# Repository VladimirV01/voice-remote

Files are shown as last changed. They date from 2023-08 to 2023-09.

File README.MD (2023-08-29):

# Voice Remote for Home Assistant
This is a ESPHome based device which can interact with voice assistants configured in Home Assistant. 

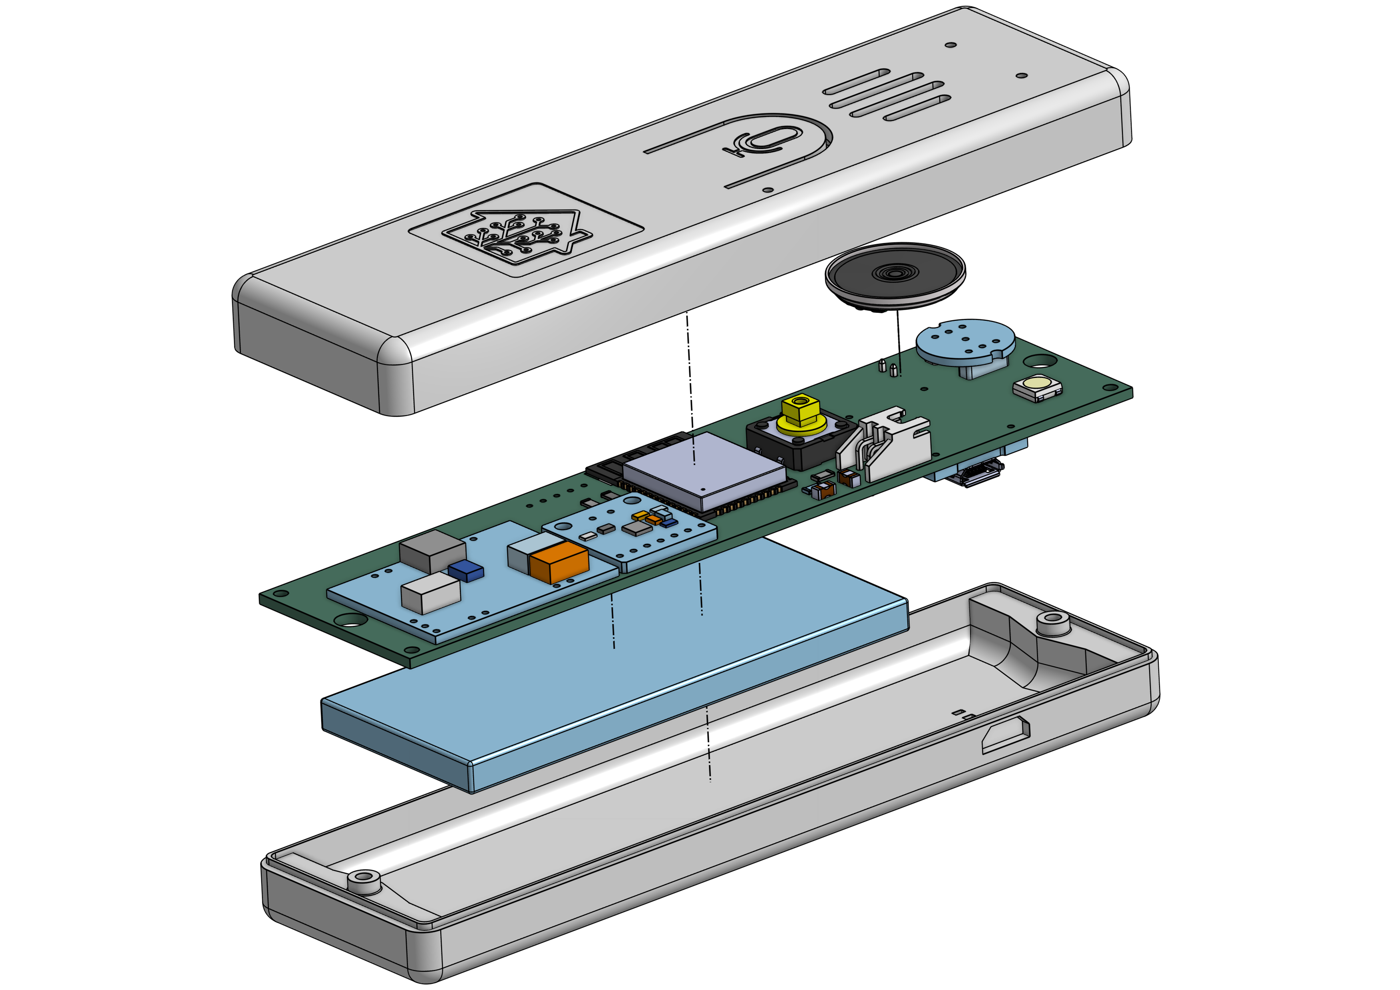
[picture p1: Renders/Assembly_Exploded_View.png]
Assembly Assembly Exploded View


## Project Timeline
Initially, I thought about this kind of project when I saw [$13 voice remote for Home Assistant](https://www.home-assistant.io/voice_control/thirteen-usd-voice-remote/) article. 

I tried to buy one **M5Stack ATOM Echo Development Kit**, but at that time it was out of stock almost everywhere I looked and it was pretty hard to source in my country. As a result, this idea transitioned to PENDING state until I manage to get an M5Stack or find a different approach. 

Some time later, thanks to the gods of youtube algorithms :smile:, I found a [video](https://www.youtube.com/watch?v=EeUG3Si9fZk) where the author describes very well an alternative for the **M5Stack ATOM kit** using **ESP32** based development board called **Adafruit Feather v2 ESP32 board**, which again was not very easy to find and source from my country.

So I decided to make my own adaptation of the project using plain ESP32 module and a custom PCB, because I like to design PCBs and I like when my projects are nice and tidy. 

___

### Main Components
- ESP32-WROOM Module
- INMP441 I2S MEMS Microphone Module
- MAX98357A I2S Amplifier
- TPS63020 Buck-Boost Converter Module
- WS2812 Addressable LED
- A tactile switch that you like (I used B3F-4055)
- A small speaker of your choice (I used AS02008MR)
- TP4056 Li-Ion Charging Module
- A Li-Ion battery (I used one from an old iPhone due to the form factor)
- Other miscellaneous components like SMD Resistors, Capacitors, etc.
___
### Case
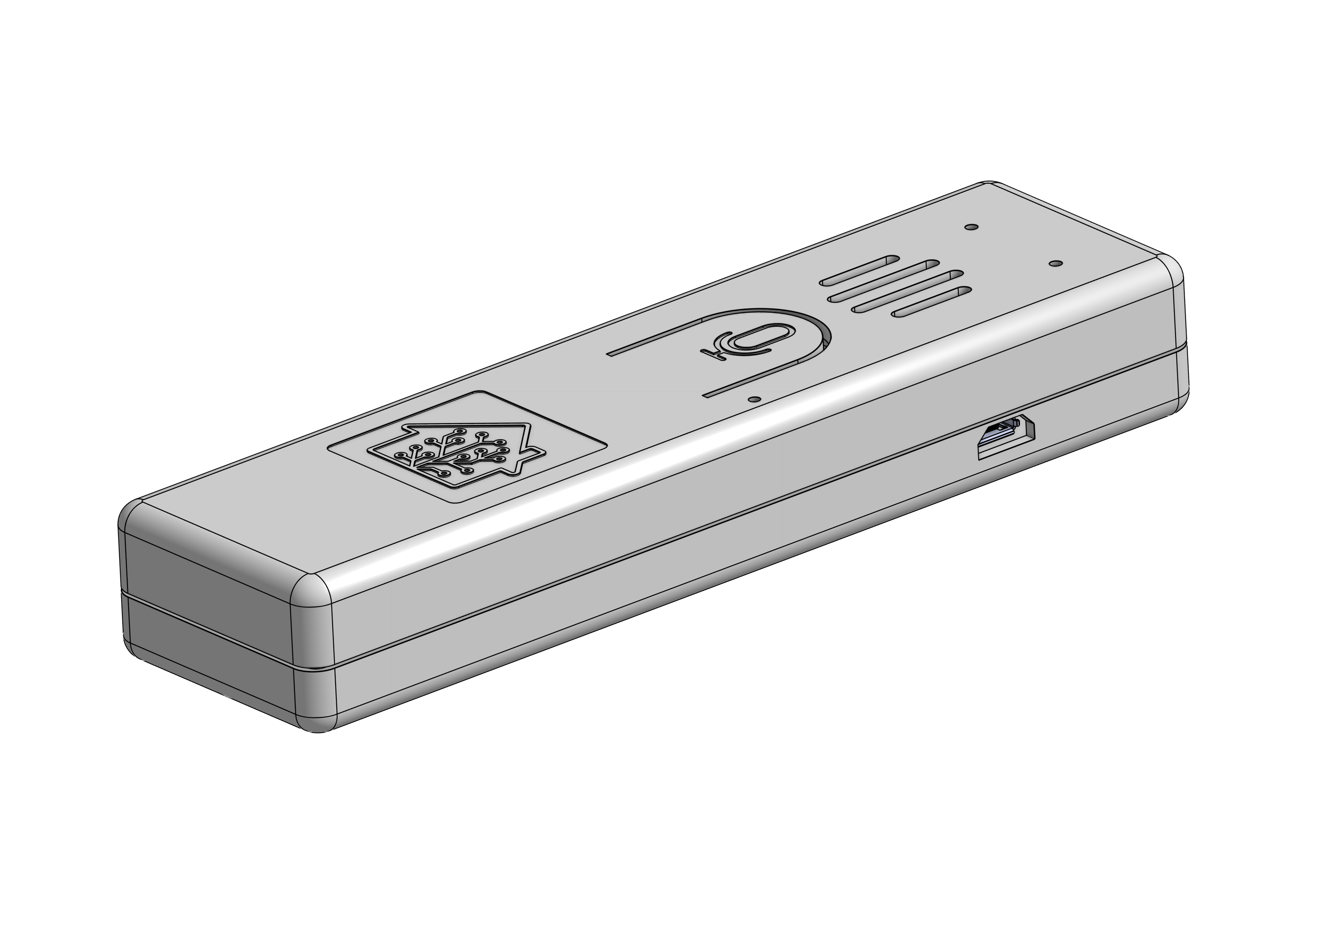
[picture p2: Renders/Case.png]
Case The Case

The case can be printed on a 3D printer without using any support, the files are attached in the "Case STL" folder. 

Also [here](https://cad.onshape.com/documents/a099e547f9d236687422ab01/w/ca8a76f6cc6eaf7c9584012f/e/bb01b9a7f8b48ed9828aac3d) is the link to the OnShape project. Anybody can make a copy and edit it if you want to make some changes to the case that will better suit your use-case.
___

### PCB
The printed circuit board was designed by me and I manufactured it using JLCPCB services and it turned out amazing. 
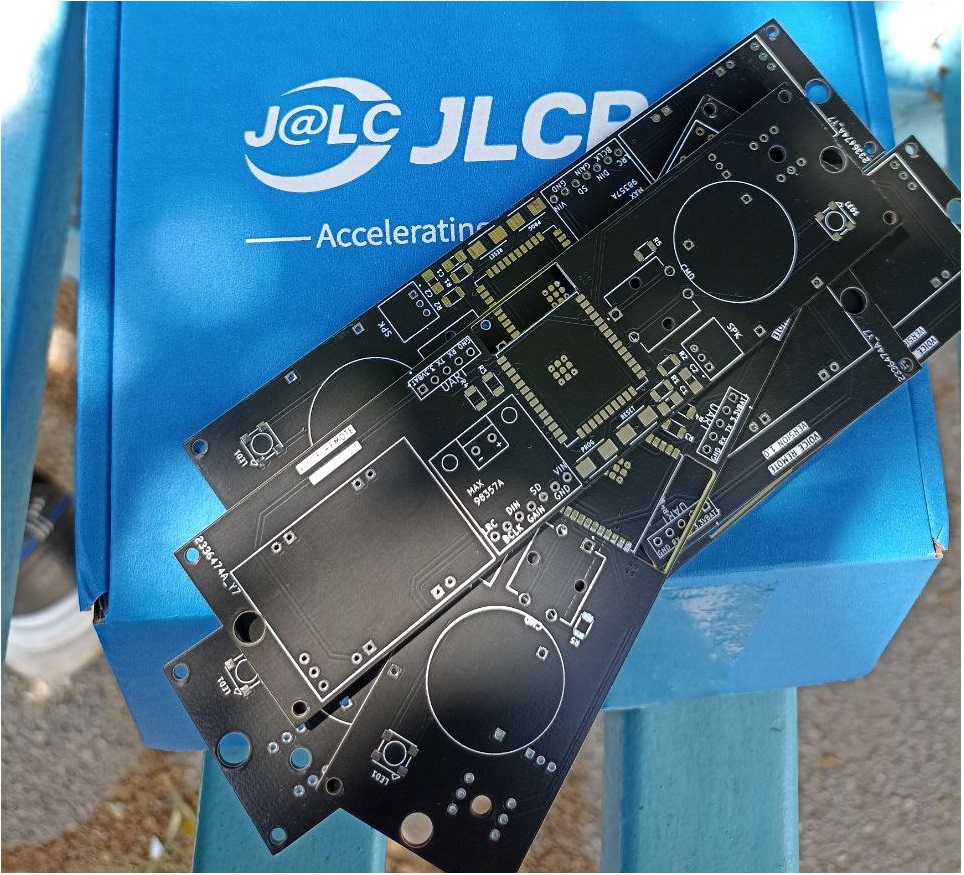
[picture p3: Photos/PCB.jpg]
PCB Printed Circuit Board

And here is it assembled.
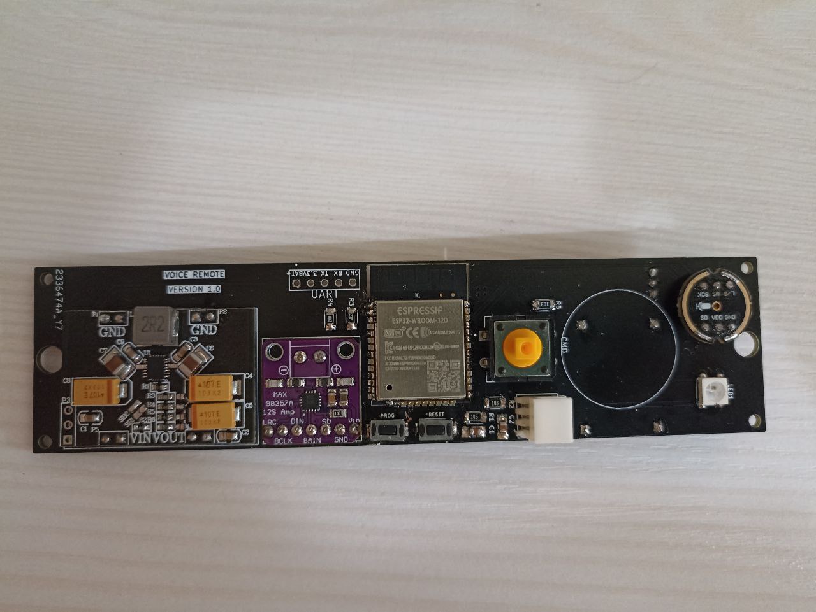
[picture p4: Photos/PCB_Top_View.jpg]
Assembled PCB Assembled Printed Circuit Board

___
### TO DO:
- Design a case adaptation for 18650 Li-Ion battery
- Remove the strapping pins (12, 15) to please my internal perfectionist and ESPHome code checker.
- Add Links to BOM

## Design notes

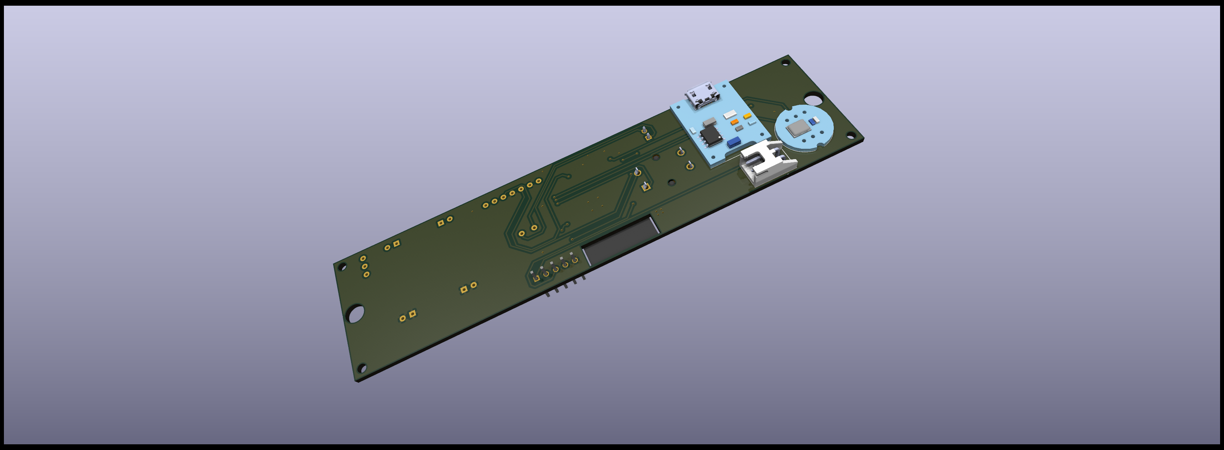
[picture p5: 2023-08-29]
Renders/KiCAD_BOTTOM.png

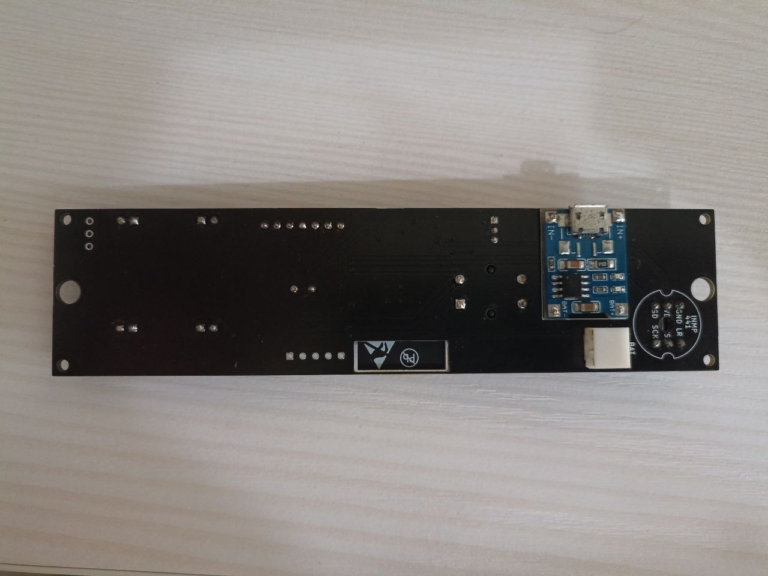
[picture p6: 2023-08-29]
Photos/PCB_Bottom_View.jpg

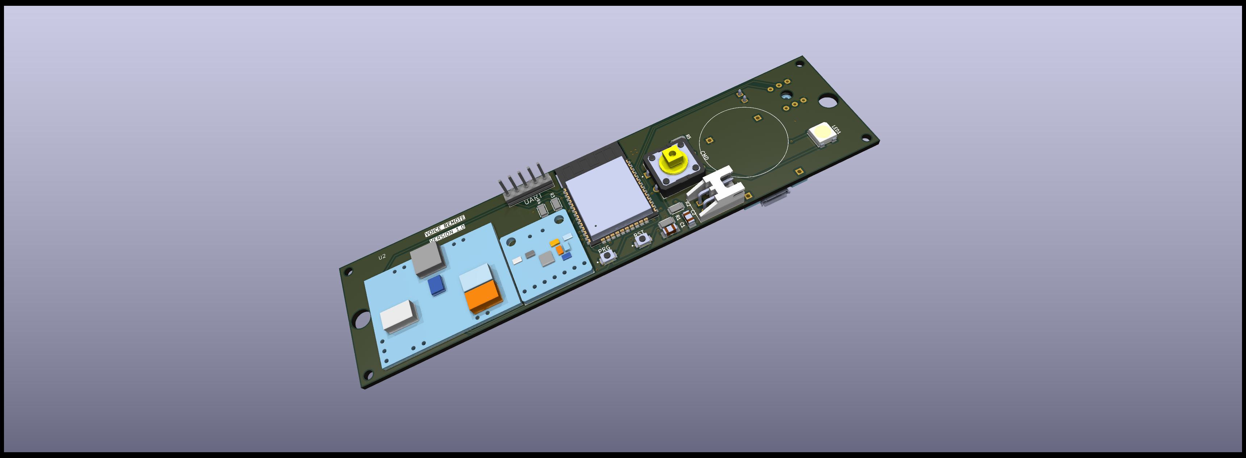
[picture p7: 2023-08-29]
Renders/KiCAD_TOP.png

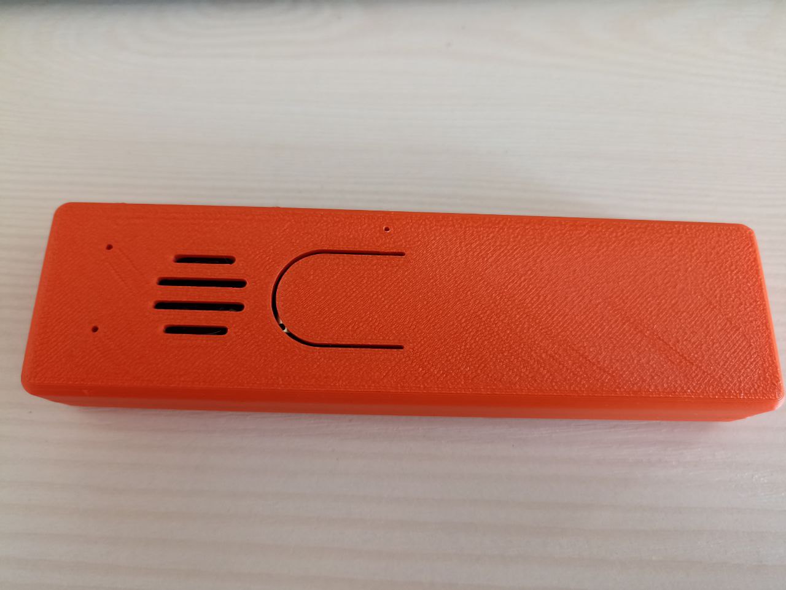
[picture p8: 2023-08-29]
Photos/Assmebly.jpg

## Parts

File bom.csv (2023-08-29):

Designator | Footprint | Quantity | Value | LCSC Part #
C1, C2 | Capacitor1206 | 2 | 0.1uF
J3 | Header_5pin | 1 | UART
LED1 | WS2812B | 1 | WS2812B
P1 | S2B-XH-A_LF__SN_ | 1 | SPK
P2 | S2B-XH-A_LF__SN_ | 1 | BAT
R1, R2, R5 | Resistor1206 | 3 | 10k
R3, R4 | Resistor1206 | 2 | 2M
S1 | B3F-4055 | 1 | CMD
S2 | Tactile_Switch_4x3x2 | 1 | RST
S3 | Tactile_Switch_4x3x2 | 1 | PRG
U1 | ESP32-WROOM-32E | 1 | ESP32-WROOM-32E
U2 | TPS63020_module | 1 | TPS63020 Module
U3 | INMP441 Module | 1 | INMP441 Module
U4 | MAX98357A Module | 1 | ~
U5 | TP4056_module | 1 | ~

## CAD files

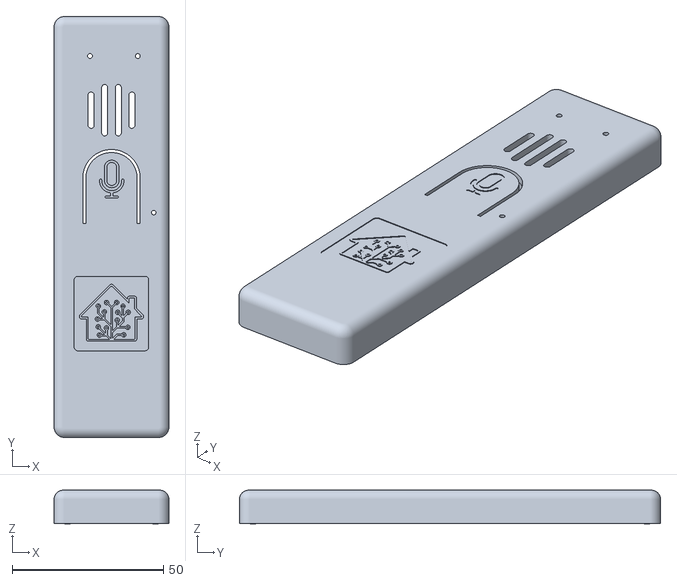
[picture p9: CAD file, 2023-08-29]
Case STL/TOP.stl
38.0 x 139.3 x 11.1

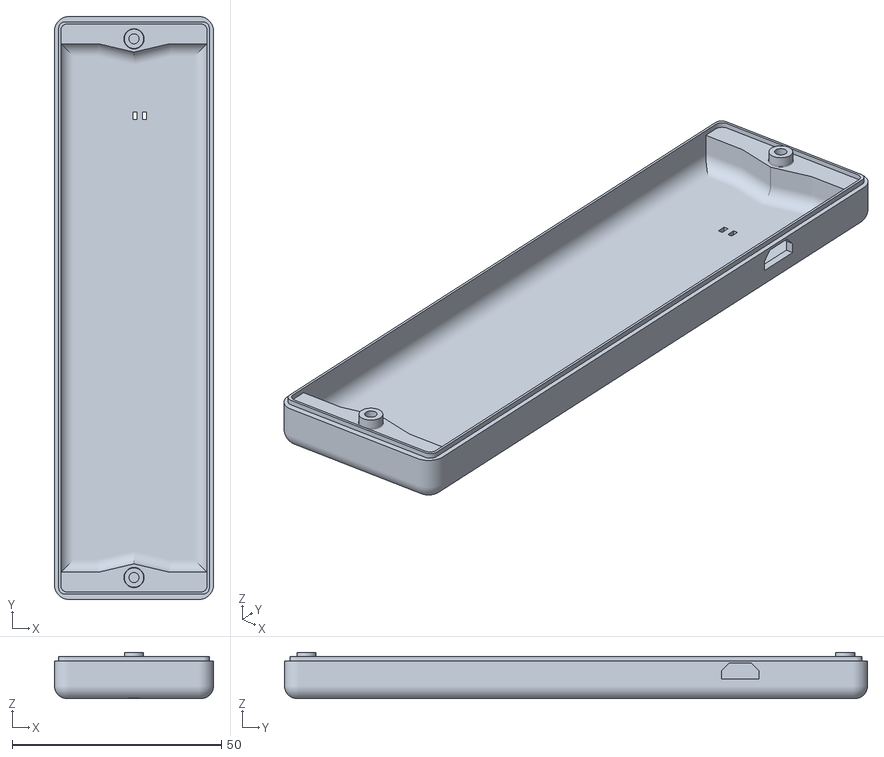
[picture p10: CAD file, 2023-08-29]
Case STL/BOTTOM.stl
38.0 x 139.3 x 11.0

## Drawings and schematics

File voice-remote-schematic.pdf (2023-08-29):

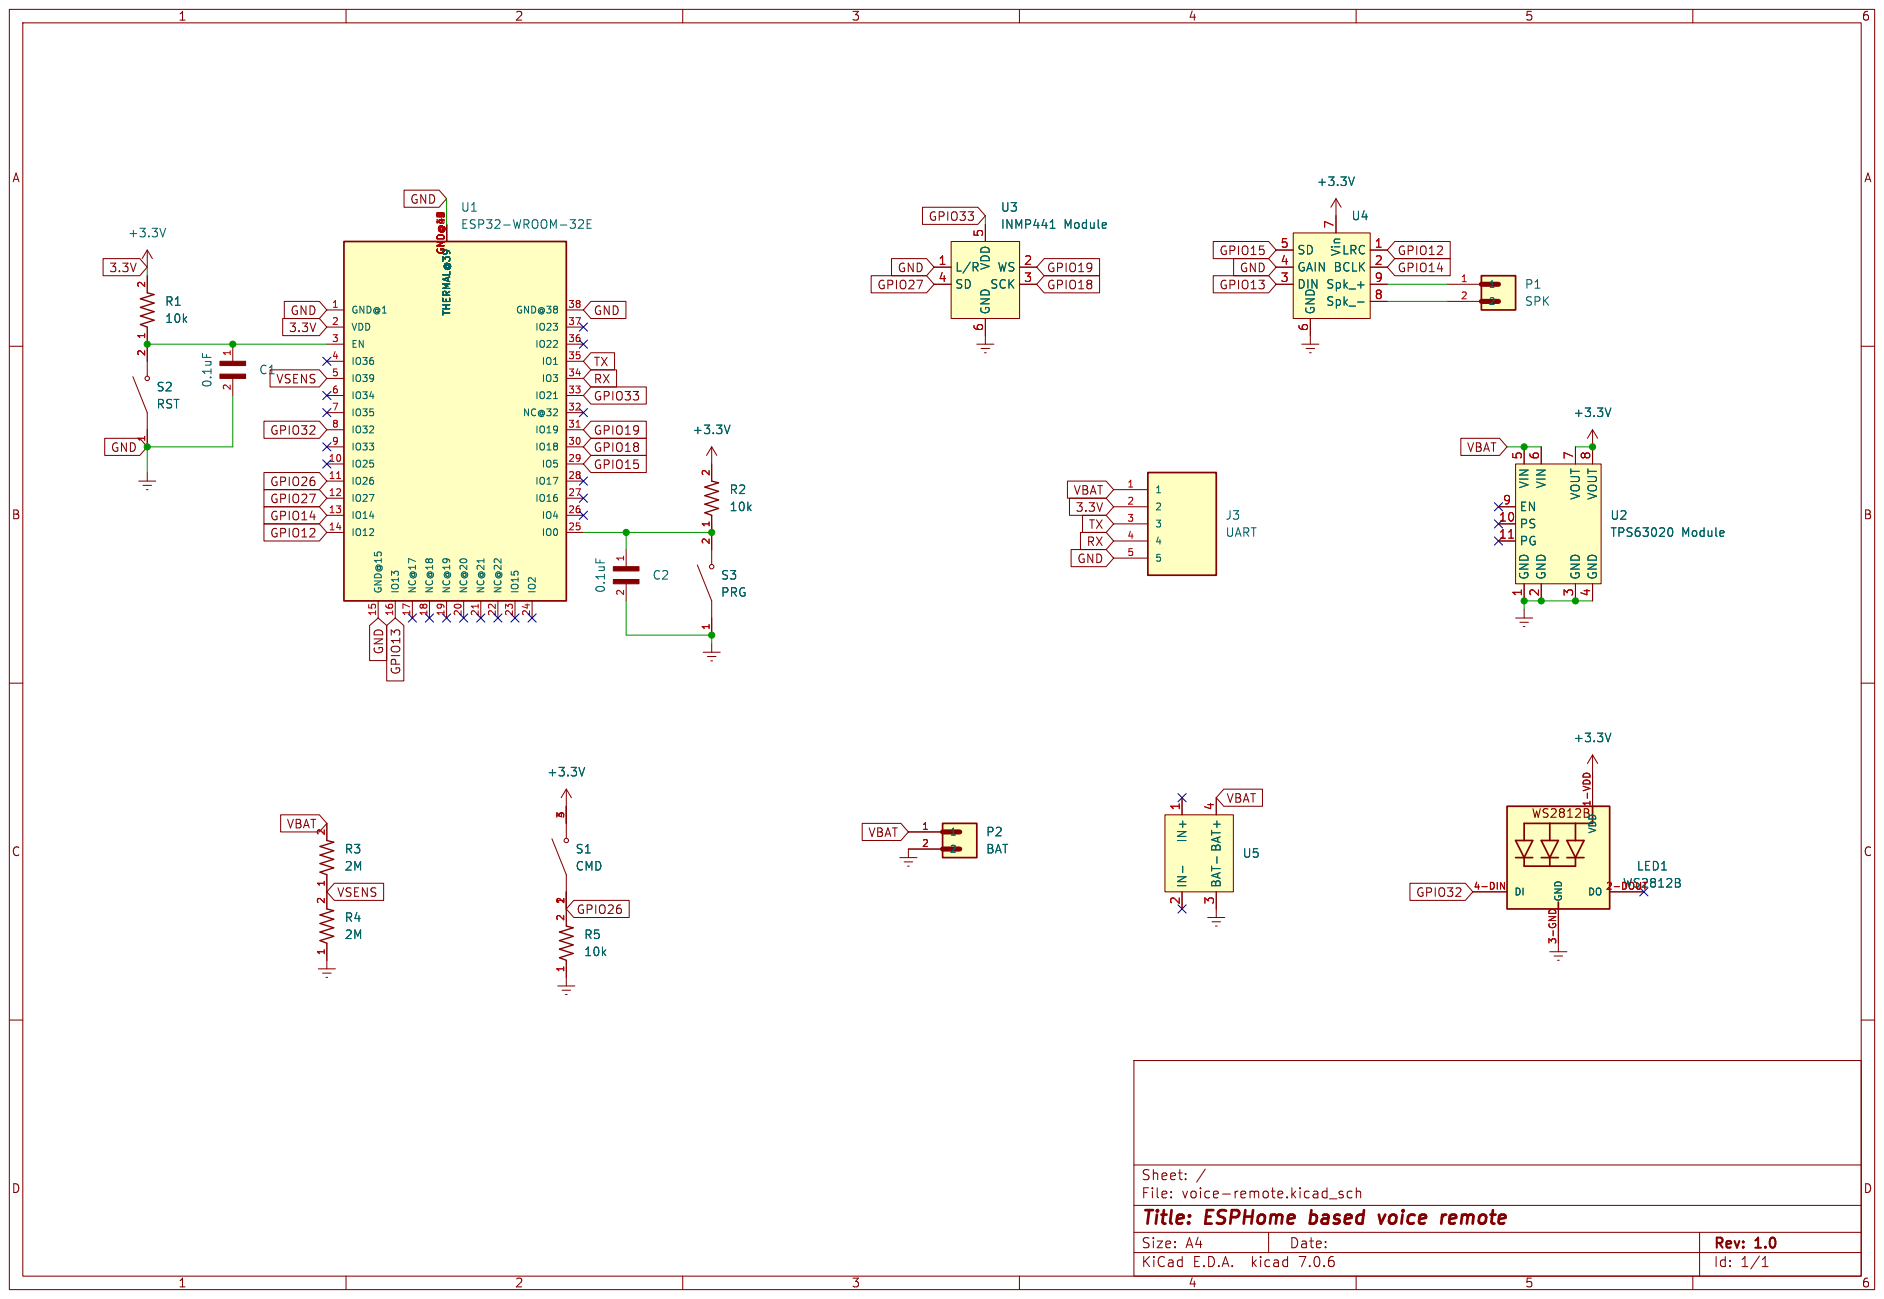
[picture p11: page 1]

DO 2-DOUT GND 3-GND

File: voice-remote.kicad_sch Sheet: /
Id: 1/1 Title: ESPHome based voice remote

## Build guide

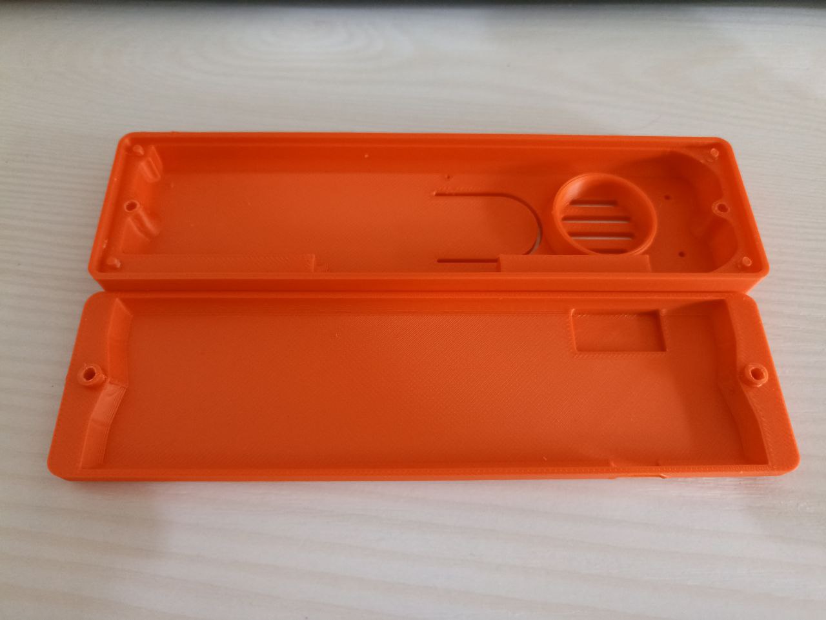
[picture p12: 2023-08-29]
Photos/Printed_case.jpg

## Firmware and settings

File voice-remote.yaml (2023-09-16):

substitutions:
  NODE_NAME: "voice-remote"
  FRIENDLY_NAME: "Voice Remote"
  LED_DATA: 'GPIO32'
  MIC_I2S_LRCLK: 'GPIO19'
  MIC_I2S_BCLK: 'GPIO18'
  MIC_DATA: 'GPIO27'
  MIC_PWR: 'GPIO33'
  AMP_I2S_LRCLK: 'GPIO12'
  AMP_I2S_BCLK: 'GPIO14'
  AMP_DATA: 'GPIO13'
  AMP_PWR: 'GPIO15'
  BAT_VSENS: 'GPIO39'
  BTN: 'GPIO26'

esphome:
  name: ${NODE_NAME}
  friendly_name: ${FRIENDLY_NAME}
  project:
    name: esp32.voice-remote
    version: "1.0"
  min_version: 2023.7.0
  on_boot:
    then:
      - script.execute: sleep_routine
      - script.execute: wifi_check

esp32:
  board: esp32dev
  framework:
    type: arduino

logger:
api:
  encryption:
    key: <EDITED>

ota:
  password: <EDITED>

wifi:
  ssid: !secret wifi_ssid
  password: !secret wifi_password
  manual_ip:
    static_ip: <EDITED>
    gateway: <EDITED>
    subnet: <EDITED>

  ap:
    ssid: "AP ${NODE_NAME}"
    password: <EDITED>

captive_portal:

light:
  - platform: esp32_rmt_led_strip
    internal: true
    rgb_order: RGB
    chipset: WS2812
    rmt_channel: 0
    id: neopixel
    pin: ${LED_DATA}
    num_leds: 1
    default_transition_length: 0ms
    effects:
      - pulse:
          transition_length: 300ms
          update_interval: 300ms

i2s_audio:
  - id: i2s_mic
    i2s_lrclk_pin: ${MIC_I2S_LRCLK}
    i2s_bclk_pin: ${MIC_I2S_BCLK}

  - id: i2s_amp
    i2s_lrclk_pin: ${AMP_I2S_LRCLK}
    i2s_bclk_pin: ${AMP_I2S_BCLK}

microphone:
  - platform: i2s_audio
    id: feather_microphone
    adc_type: external 
    i2s_audio_id: i2s_mic 
    i2s_din_pin: ${MIC_DATA}
    pdm: false

speaker: # Media player won't work currently with Piper, have to use speaker component. Media player works with cloud.
  - platform: i2s_audio
    id: media_out
    dac_type: external
    i2s_audio_id: i2s_amp
    i2s_dout_pin: ${AMP_DATA}
    mode: mono

sensor:
  - platform: adc
    pin: ${BAT_VSENS}
    name: "Battery Voltage"
    update_interval: 20s
    attenuation: 11db # Required
    filters:
     - multiply: 2.0
     - offset: 0.00 # Trim reading by adjusting this value

output:
  - platform: gpio
    pin: ${AMP_PWR}
    id: Amp_Power

  - platform: gpio
    pin: ${MIC_PWR}
    id: Mic_Power

voice_assistant:
  microphone: feather_microphone
  speaker: media_out
  silence_detection: true
  on_listening:
    - light.turn_on: 
        id: neopixel
        color_brightness: 50%
        red: 0%
        green: 100%
        blue: 0%
        effect: pulse
    - output.turn_on: Mic_Power 
    - output.turn_on: Amp_Power
  on_tts_start:
    - light.turn_on: 
        id: neopixel
        color_brightness: 50%
        red: 0%
        green: 0%
        blue: 100%
        effect: pulse
  on_tts_end:
    - light.turn_on: 
        id: neopixel
        color_brightness: 50%
        red: 0%
        green: 0%
        blue: 100%
        effect: pulse
  on_end:
    - delay: 100ms
    - wait_until:
        not:
          speaker.is_playing: media_out
    - light.turn_off: neopixel
    - output.turn_off: Mic_Power # Power off Mic when not used
    - output.turn_off: Amp_Power # Uses Amp SD pin to shut off amp when not being used.
  on_error:
    - light.turn_on: 
        id: neopixel
        color_brightness: 100%
        red: 100%
        green: 0%
        blue: 0%
        effect: none
    - delay: 1s
    - light.turn_off: neopixel #set status LED to blank, to clear VA status and prep for Wifi check

binary_sensor:
  - platform: status # This sensor just says "Connected" or "Not Connected" in the homeassistant.
    name: "Voice Remote Status"
  
  - platform: homeassistant # This imports the input boolean from the homeassistant to check if there is pending update
    id: update
    entity_id: input_boolean.esphome_pending_update

  - platform: gpio
    pin:
      number: ${BTN}
      inverted: False
    name: Button
    id: remote_button
      filters:
        - delayed_on: 10ms # Debounce time
    on_press: 
      then:
        - script.stop: sleep_routine # This resets the sleep timer every time the button is pressed
        - logger.log: "Sleep timer reset."
        - script.execute: sleep_routine
    on_multi_click:
    - timing:
        - ON for 1s to 2s
        - OFF for at least 0.5s
      then:
        - logger.log: "Starting Voice Assistant in continuous mode."
        - voice_assistant.start_continuous:
    - timing:
        - ON for at most 1s
        - OFF for at least 0.5s
      then:
        - if:
            condition: voice_assistant.is_running
            then:
              - logger.log: "Stopping Voice Assistant"
              - voice_assistant.stop:
            else:
              - logger.log: "Starting Voice Assistant"
              - voice_assistant.start:
              
deep_sleep:
  id: deep_sleep_1
  sleep_duration: 3h # how long to sleep before rewaking
  esp32_ext1_wakeup: #regular GPIO wakeup had some issues on some boards. Ext1 seems to work on everything.
    pins:
      - ${BTN}
    mode: ANY_HIGH
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
